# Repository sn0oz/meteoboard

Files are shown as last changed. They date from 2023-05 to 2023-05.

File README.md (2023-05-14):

mb-logo

# meteoboard - colorful weather forecast visualization 

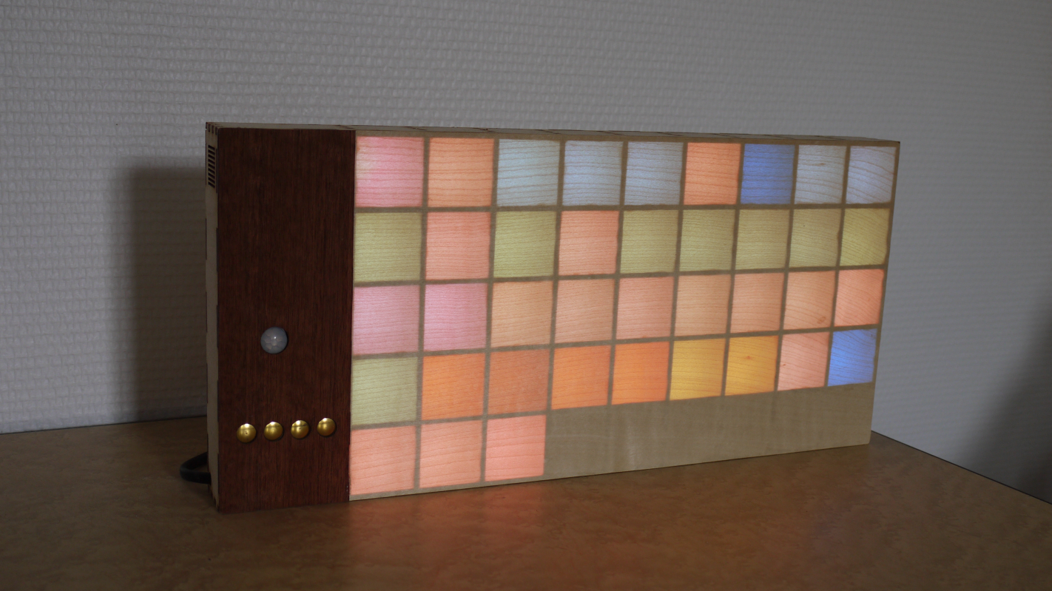
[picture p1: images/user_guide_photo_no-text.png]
mb-photo
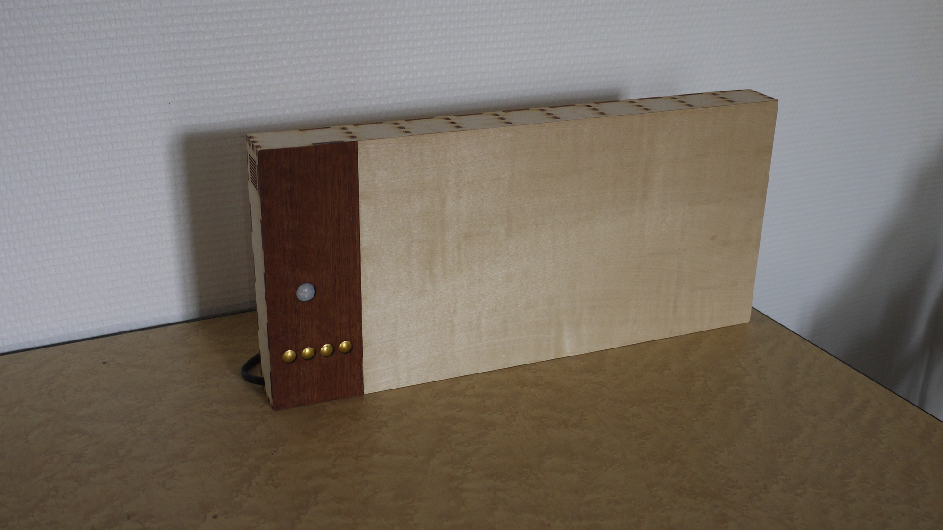
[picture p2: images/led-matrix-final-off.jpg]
mb off


meteoboard is a LED matrix displaying weather forecast with color mapping to weather condition or temperature values. for example sunny weather is obviously yellow and rain condition is represented with 3 shades of blue. see the user guide for detailed color/value mapping.
with a bit of practice it allows an instant knowledge of weather forecast, on a decorative object.

<figure>
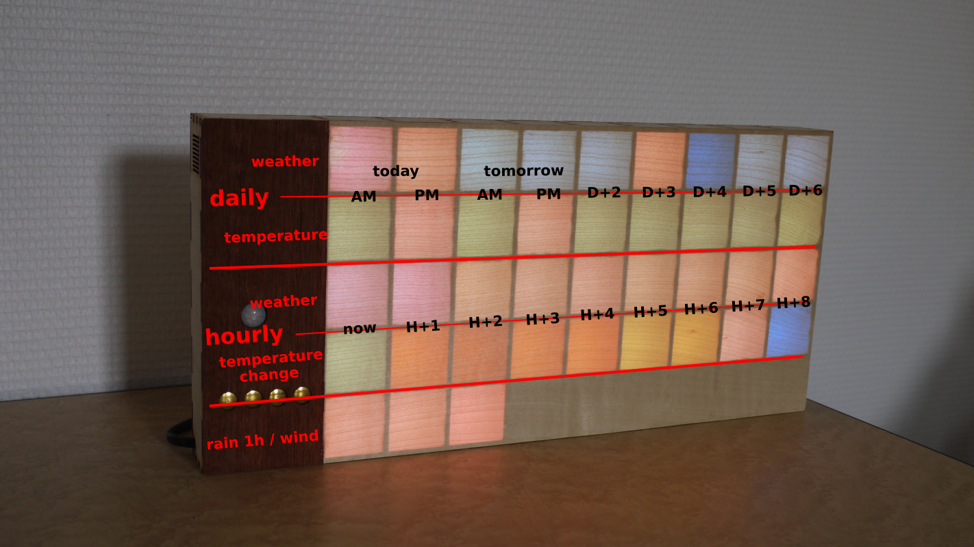
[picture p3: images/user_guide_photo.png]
user guide
    
    <figcaption>user guide</figcaption>
</figure>
<figure>
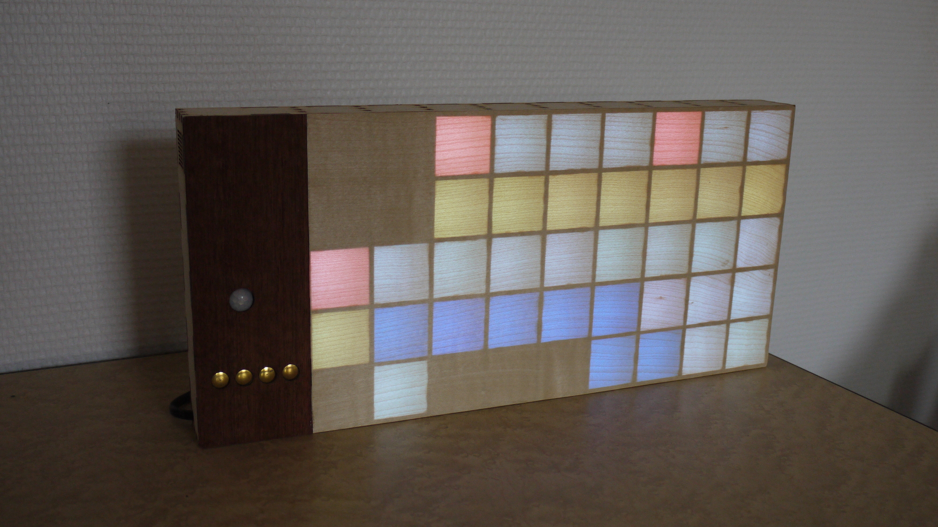
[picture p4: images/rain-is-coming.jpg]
rain is coming
    
    <figcaption>rain is coming</figcaption>
</figure>

the LED matrix can also be used to display various animations.

inspired by [maketvee's Wooden LED Gaming Display](https://www.instructables.com/Wooden-LED-Gaming-Display-Powered-by-Raspberry-Pi-/)

## features
- daily, hourly weather and temperature forecast + rain in the hour / current wind
- 4 touch buttons to control the display (change city, animation, ...)
- PIR and ambient light sensors to switch on only when necessary, at the right brightness

## usage

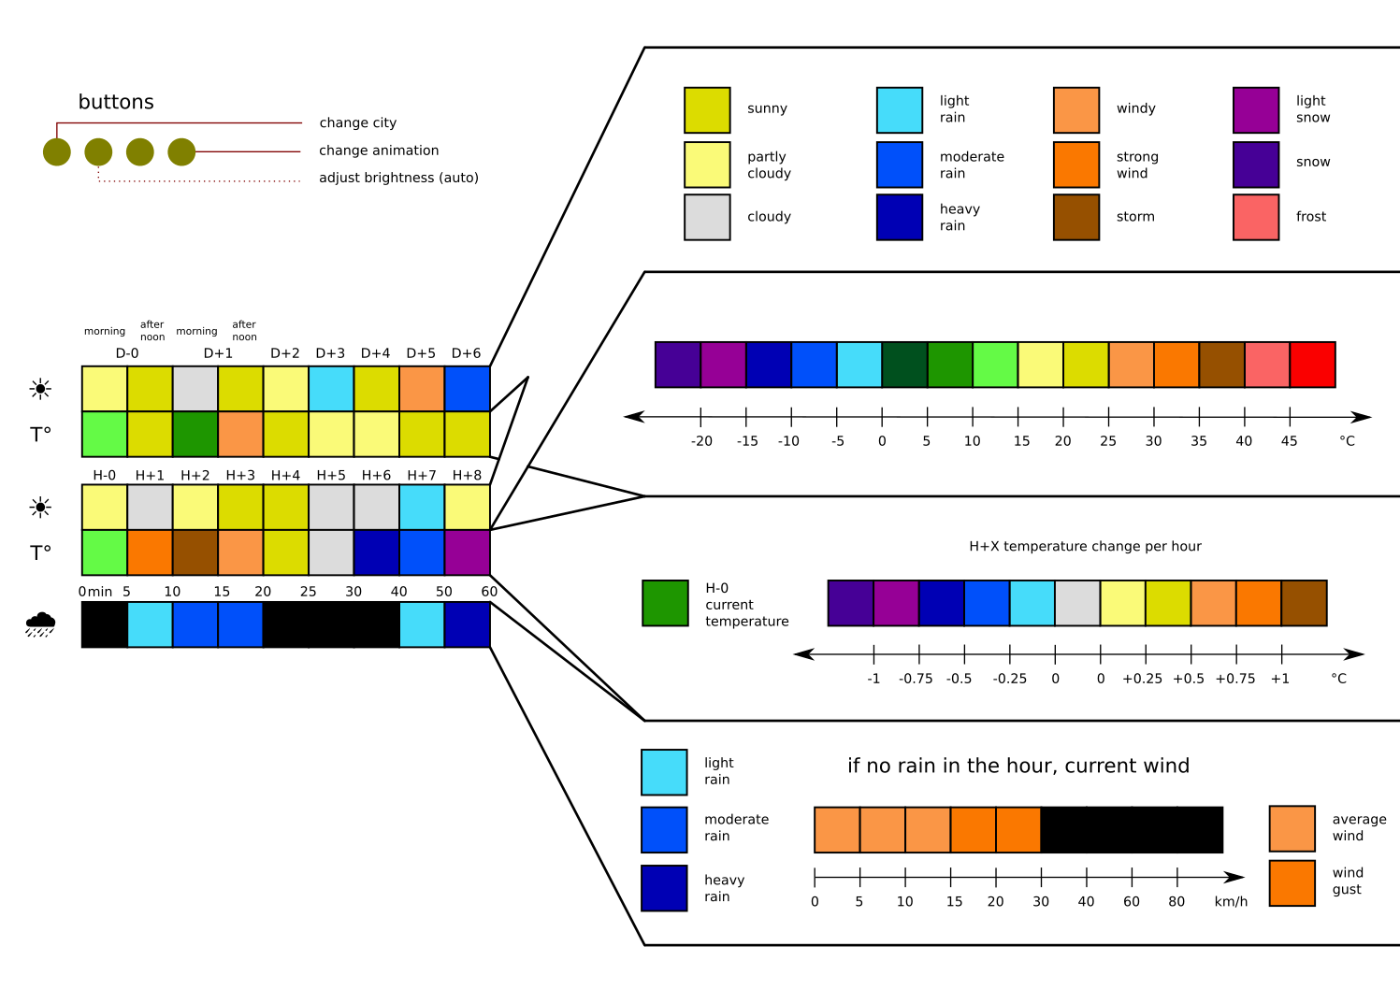
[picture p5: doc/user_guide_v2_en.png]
user guide en


## hardware

### case
[parametric wooden LED matrix](3d/)

### PCB
designed with KiCad
based on ESP32 it includes the sensors and allows to easily connect the LED strips.

## software
needs cleanup before releasing...

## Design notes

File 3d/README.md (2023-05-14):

# a parametric, veneer covered wooden LED matrix

includes casing for custom PCB based on ESP32 featuring LED driver, PIR and ambient light sensors, and touch buttons.
it can be wall mounted or just put on a flat surface.

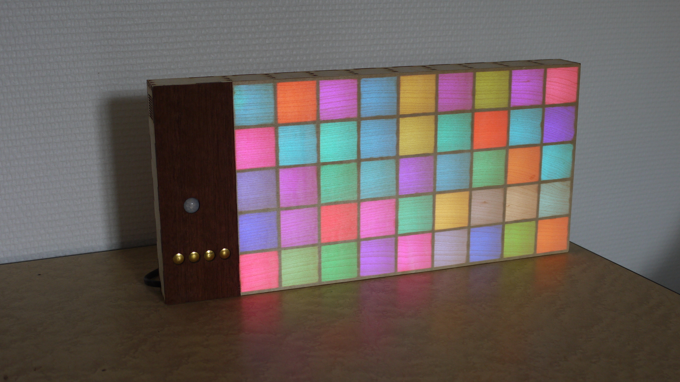
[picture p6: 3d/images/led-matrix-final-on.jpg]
led-matrix-final-on
led-matrix-final-off

inspired by: [maketvee's Wooden LED Gaming Display](https://www.instructables.com/Wooden-LED-Gaming-Display-Powered-by-Raspberry-Pi-/)
assisted by scripts from: [scottbez1's split-flap](https://github.com/scottbez1/splitflap/)

intended for weather forecast display but can be used for anything fitting the small resolution.

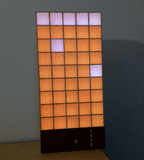
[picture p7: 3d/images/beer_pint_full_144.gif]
beer pint animation
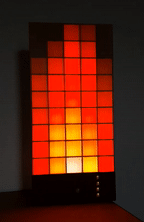
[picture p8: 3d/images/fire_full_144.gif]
fire animation


## **usage**
set parameters at the beginning of **board.scad** according to your needs. many parameters are available, including matrix resolution, wood thickness, kerf, ...
run **scripts/generate_2d.py** to generate SVG files for laser etching/engraving/marking/cutting.
you can adjust the kerf to fit your laser and other parameters with the script arguments.
the script render the 2d view of board.scad file and optimize the laser cutting by removing redundant lines.

## **recommended parameters**
the main dimension driver is the LED strip interval, which correspond to pixel height and width.
designed for 30 LED/m strip (33.3mm interval), it should be possible to use 60 or 15 LED/m strips however LED brightness might be insufficient for the later, depending on the veneer's light transmission.
however any pixel dimension is possible with other strip interval or by using standalone LEDs.
adjust the LED interval in led_ADA1376_dimensions.scad file accordingly.

## **design**
the parts placement is optimized to fit 2 A3 plywood sheets for a 9x5 pixels matrix.
if you change this resolution you might need to modify the last part of the board.scad script to fit your own resolution vs sheet dimensions.

### veneer
I used sycomore 0.3mm veneer - 0.6mm should allow enough light transmission.
choose whitest available wood veneer to limit color drift (can be compensated on software).

### touch buttons
intended to be hidden behind veneer, however extension veneer (0.6mm thick) doesn't allow reliable touch detection. 0.3mm veneer might work with carefull tuning of detection values to prevent false positive or undetected touches. I found it was easier to just cut the veneer and make buttons visible, while visually acceptable with their brass tacks shining.

### laser
adjust your laser parameters for each color/mode:
black: etch
orange: engrave (~1mm)
blue: mark
red: cut

## **assembly**
cut LED strip to length and lay on the back panel according to marking, taking care of data direction, **starting from top left**.
solder power and data cables: each strip is directly connected to power source, data follow a zig-zag way from top left.

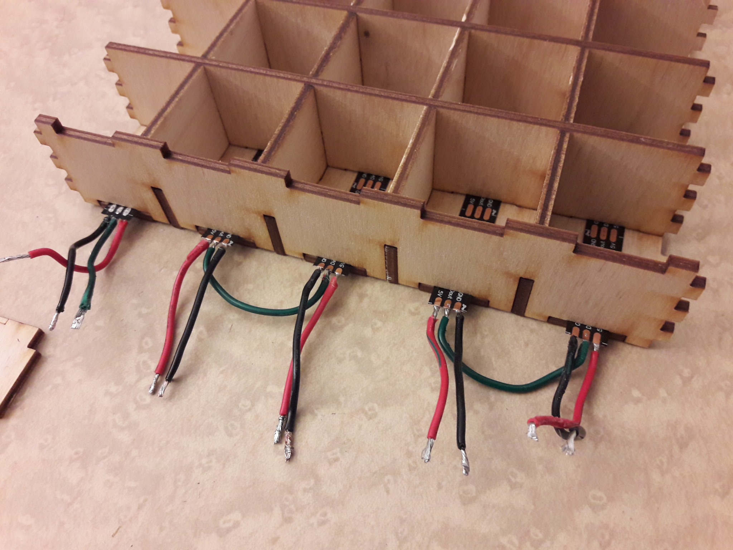
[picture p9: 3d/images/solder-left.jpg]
solder left
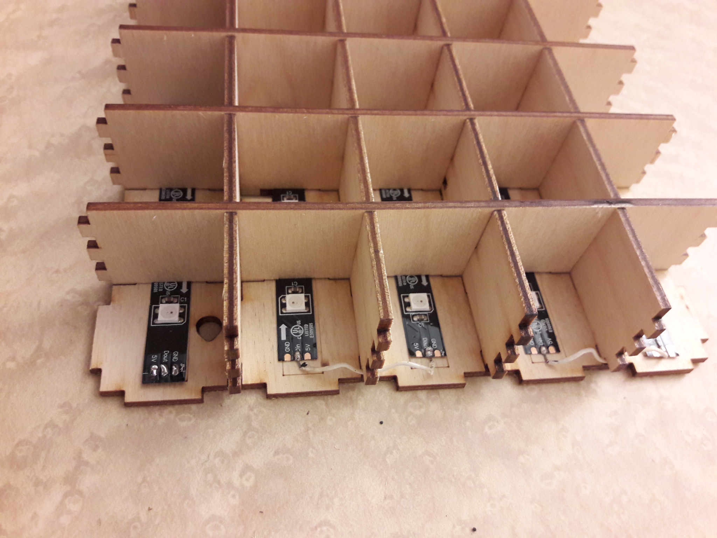
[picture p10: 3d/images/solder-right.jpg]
solder right


assemble the horizontal spacers first then vertical spacers

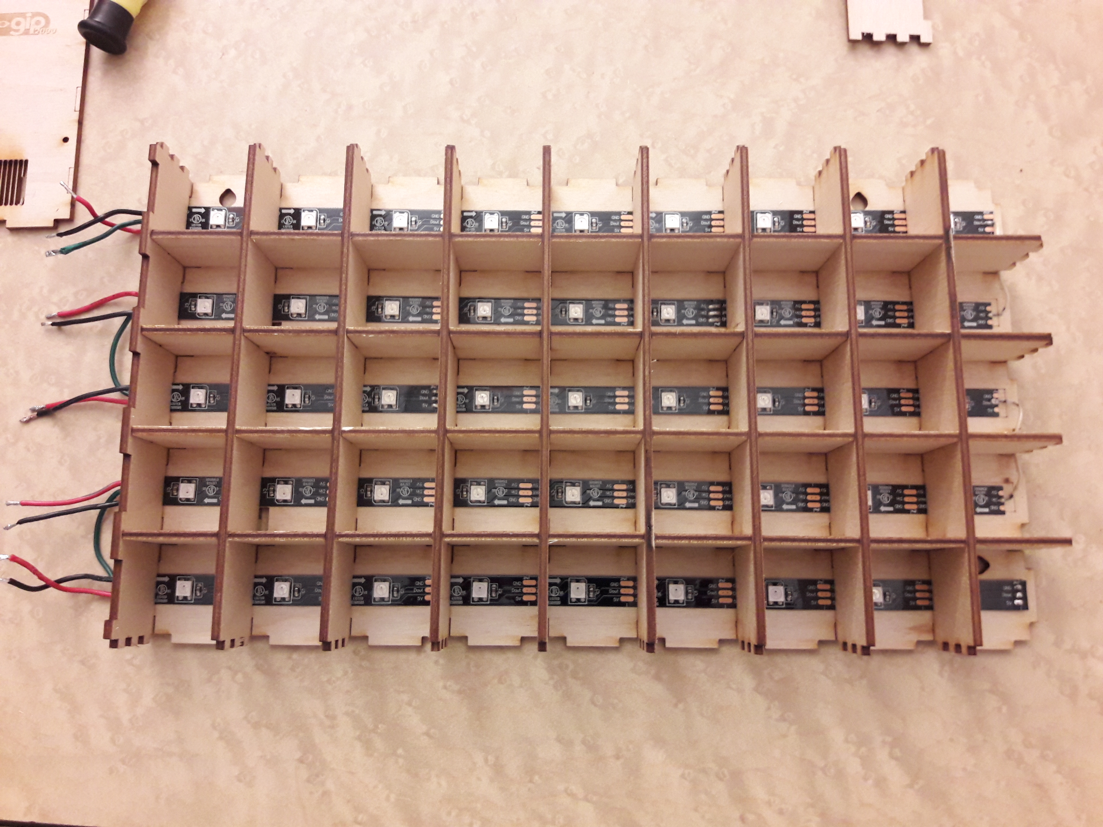
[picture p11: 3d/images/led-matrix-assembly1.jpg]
led-matrix-assembly1


then add the border panels, and the extension front panel (supporting the PCB).

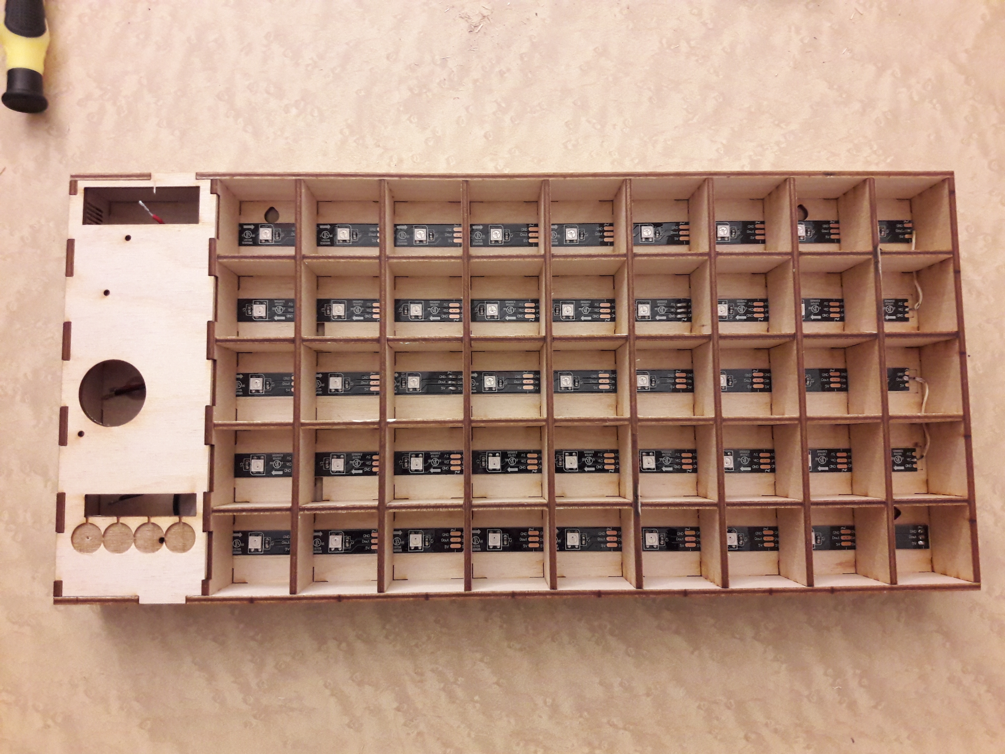
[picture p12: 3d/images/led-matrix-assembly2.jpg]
led-matrix-assembly2
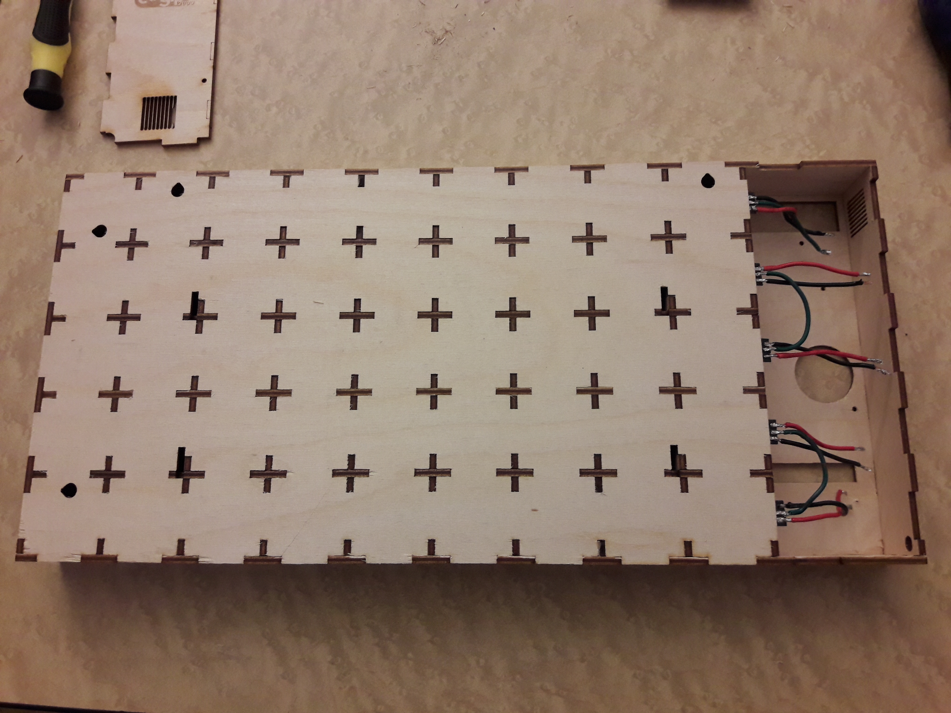
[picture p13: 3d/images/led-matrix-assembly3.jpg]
led-matrix-assembly3

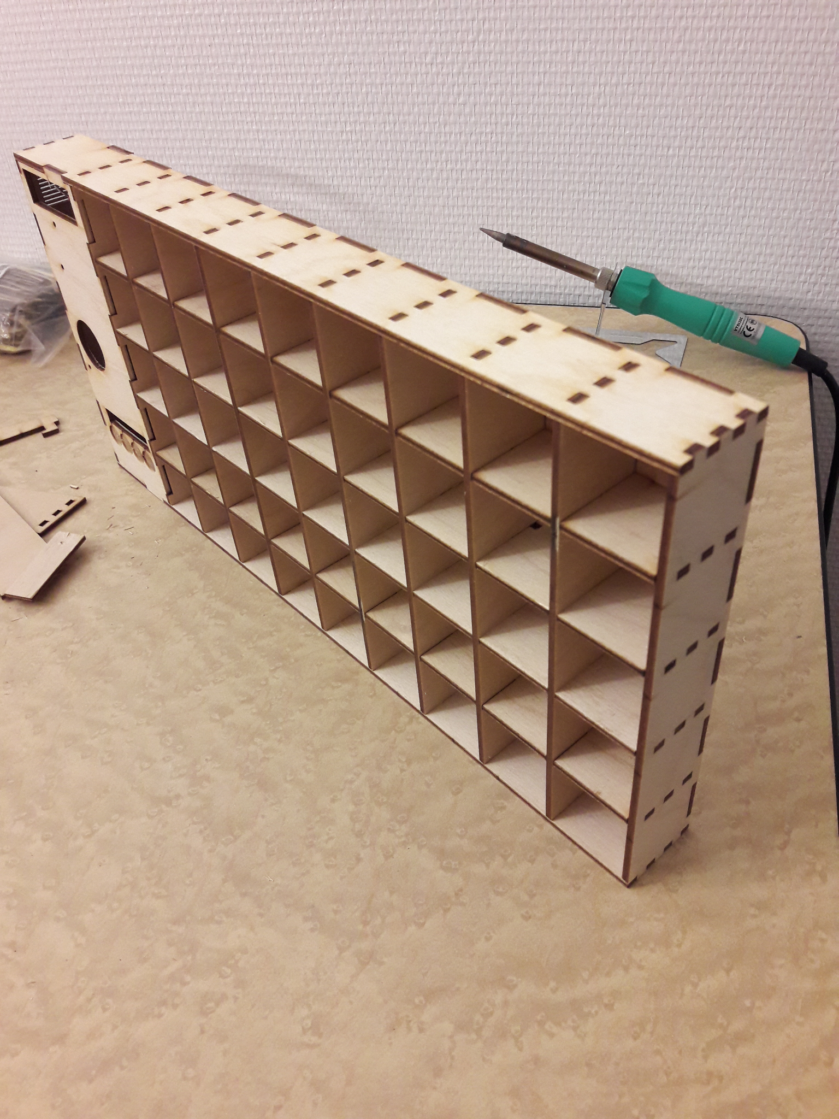
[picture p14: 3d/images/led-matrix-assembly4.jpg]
led-matrix-assembly4


place and connect the PCB, touch buttons (made from tacks with attached cables connected to GPIOs).

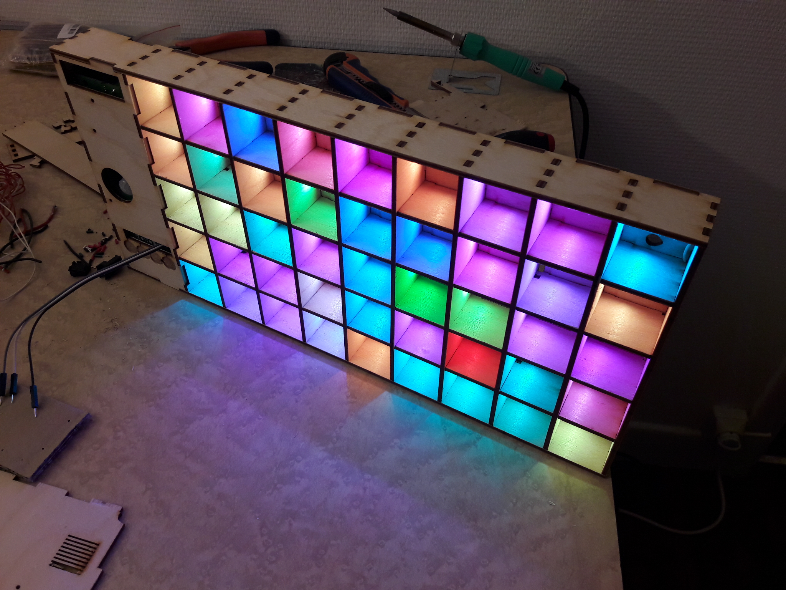
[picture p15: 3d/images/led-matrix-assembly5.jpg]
led-matrix-assembly5


eventually glue the wood veneer. I chose to use different woods for extension and LED matrix but you can use the same veneer (parameterized on the board.scad file).

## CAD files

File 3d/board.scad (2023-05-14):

use<pcb_MB2.scad>;
use<pir_SBC.scad>;
use<led_ADA1376.scad>;
use<label.scad>;
use<projection_renderer.scad>;

include<pcb_MB2_dimensions.scad>;
include<psu_IRM-15-X_dimensions.scad>;
include<pir_SBC_dimensions.scad>;
include<led_ADA1376_dimensions.scad>;

version = "2.1.1";

testing = false;
explosion = 0;

render_3d = true;
render_back_panel = true;
render_electronics = true;
render_front_panel_veneer = true;
render_unmounted_support = true;

// board parameters
pixels_h = 9;
pixels_v = 5;
thickness = 3;
veneer_thickness = 0.3;
num_touch_buttons = 4;
touch_button_radius = 4.5;
front_panel_bicolor = true;
pixel_width = led_interval;
pixel_height = pixel_width;
echo(pixel_width = pixel_width);

// assembly parameters
side_panel_num_notches = 7;
pcb_num_notches = 5;
bp_notch_length = 6;
pcb_clearance = 1;
cable_clearance = 12;
vents_number = 7;
vents_width = 1;
power_cable_position = 0;   // 0 = both, 1 = left, 2 = bottom
power_cable_hole_radius = 3;
buttons_height = pixel_height + thickness;
logo_scale_factor = 1.5;

// 2d parameters
render_index = -1;
render_etch = true;
render_mark = true;
render_engrave = true;
panel_horizontal = 0;
panel_vertical = 0;
render_2d_mirror = false;
a3_fit_offset = 20;

// Remember: it's better to underestimate (looser fit) than overestimate (no fit)
kerf = 0.12;

$fn = 60;

wood = [0.76, 0.6, 0.42];
sycomore = [0.9, 0.85, 0.75];
cherrywood = [0.2, 0.15, 0.2];
etch_color = [0, 0, 0];
mark_color = [0.2, 0.4, 0.6];
engrave_color = [0.85, 0.4, 0];

etch_depth = 0.1;
mark_depth = 0.1;
engrave_depth = 0.1;

// "Epsilon" - a small error tolerance value, used when designing 3d parts to avoid 
// exact complanar faces that cause OpenSCAD rendering artifacts
// See https://3dprinting.stackexchange.com/a/9795
eps = 0.01;

// CHANGELOG v2.1.1
// wall mounted holes gap identical for horizontal and vertical positions
// separator_v0 led cable notches
// power cable hole choice


// TODO: mark helpers and reminders (separators, ...)



// PCB position
pcb_x = thickness + pcb_clearance;
pcb_y = thickness + cable_clearance/2;

// board dimensions
extension_width = pcb_x + pcb_width + cable_clearance;
echo(extension_width = extension_width);

board_height = thickness + pcb_height + psu_height + pcb_clearance + thickness;
echo(board_height=board_height);
board_width = pixels_v*pixel_height + thickness;
echo(board_width = board_width);
board_length = extension_width + pixels_h*pixel_width + thickness;
echo(board_length = board_length);

// common notch width for panel assembly
notch_width = board_height / side_panel_num_notches;

// unmounted support height
um_support_h = (pixels_v-2)*pixel_height + 4*thickness;


if (!testing) {
    assert(board_width >= pcb_y + pcb_length + pcb_clearance,
                                                "Insufficient panel height for PCB !");
    assert(board_length + extension_width + 2*kerf < 418,
                                                "A3 part 1 length overrun !");
    assert(12*board_height + 11*kerf < 416,
                                                "A3 part 2 length overrun !");
    assert(board_width + 3*board_height + 3*kerf < 293,
                                                "A3 part 1 width overrun !");
    assert(board_width + um_support_h + kerf < 293,
                                                "A3 part 2 width overrun !");
}



module copyleft() {
    text(text=str("meteoboard v", version), font = "Roboto", size = 4, valign = "center",
                                                halign = "center");
}

module logo(scale_factor, centered = false) {
    logo_length = 6;
    logo_width = 5;
    if (centered) {
        translate([-logo_length*scale_factor/2, -logo_width*scale_factor/2])
            scale([scale_factor, scale_factor])
                import("images/mb_logo_b&w.svg");
    }
    else {
        scale([scale_factor, scale_factor])
            import("images/mb_logo_b&w.svg");
    }
}

module laser_mirror() {
    if (render_2d_mirror) {
        mirror([1, 0, 0])
            children();
    }
    else {
        children();
    }
}

module laser_etch_style() {
    color(etch_color)
        linear_extrude(height=etch_depth)
            children();
}

module laser_mark_style() {
    color(mark_color)
        linear_extrude(height=mark_depth)
            children();
}

module laser_engrave_style() {
    color(engrave_color)
        linear_extrude(height=engrave_depth)
            children();
}

module air_vents_2d() {
    hull() {
        translate([0, vents_width/2])
            circle(vents_width/2);
        translate([board_height-5*thickness-vents_width, vents_width/2])
            circle(vents_width/2);
    }
}

module wall_mount_hole() {
    hull() {
        circle(3);
        translate([0, 3])
            circle(1);
    }
}

module hook() {
    union() {
        square([3*thickness, 2*thickness]);
        translate([2*thickness, -thickness])
            square(thickness);
    }
}

module unmounted_support_cap() {
    color(wood) {
        linear_extrude(height=thickness) {
            union() {
                hook();
                translate([2*thickness, 2*thickness])
                    square(thickness);
            }
        }
    }
}

module unmounted_support() {
    color(wood) {
        linear_extrude(height=thickness) {
            difference() {
                h = um_support_h;
                union() {
                    polygon([[-board_height,0], [0,0], [0,h], [-2*thickness,h]]);
                    translate([0, pixel_height + thickness])
                        hook();
                    translate([0, h - 3*thickness])
                        hook();
                }

                // link notches
                for (i = [2:2:side_panel_num_notches-1]) {
                    translate([-notch_width*i, thickness])
                        square([notch_width, thickness]);
                }
            }
        }
    }
}


module unmounted_support_link() {
    color(wood) {
        linear_extrude(height=thickness) {
            difference() {
                len = (pixels_h-3)*pixel_width + thickness;
                square([len, board_height]);
                
                // unmounted support notches
                for (i = [0:2:side_panel_num_notches-1]) {
                    translate([0, notch_width*i])
                        square([thickness, notch_width]);
                    translate([len - thickness, notch_width*i])
                        square([thickness, notch_width]);
                }
            }
        }
    }
}


module extension_panel_2d() {
    difference() {
        square([extension_width - kerf, board_width]);
        
        // side panel notches
        for (i = [0:pixels_v]) {
            translate([0, i*pixel_width - bp_notch_length])
                square([thickness, 2*bp_notch_length + thickness]);
        }
        
        // top & bottom panel notches
        translate([extension_width - bp_notch_length, 0])
            square([bp_notch_length, thickness]);
        translate([extension_width - bp_notch_length, board_width - thickness])
            square([bp_notch_length, thickness]);
        square([extension_width - pixel_width + bp_notch_length + thickness, thickness]);
        translate([0, board_width - thickness])
            square([extension_width - pixel_width + bp_notch_length + thickness, thickness]);
    }
}


module extension_back_panel() {
    // takedown back panel for maintenance
    color(wood) {
        linear_extrude(height=thickness) {
            difference() {
                extension_panel_2d();

                // screw holes
                for (i = [1, pixels_v-1]) {
                    translate([extension_width - thickness, 
                                        pixel_height*i + thickness/2])
                        circle(1);
                }

                // air vents
                for (i = [0:vents_number-1]) {
                    translate([(extension_width - 5*thickness + vents_width)/2,
                                            3*thickness + (2*i+1)*vents_width])
                        air_vents_2d();
                }
                

                // power cable hole
                translate([thickness + 0.5*power_cable_hole_radius, thickness + 0.5*power_cable_hole_radius])
                    circle(1.25*power_cable_hole_radius);
            }
        }
    }
}


module extension_front_panel() {
    // PCB support panel
    color(wood) {
        linear_extrude(height=thickness) {
            difference() {
                union() {
                    extension_panel_2d();
                    translate([extension_width - kerf, thickness])
                        square([kerf + thickness, board_width - 2*thickness]);                
                }
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

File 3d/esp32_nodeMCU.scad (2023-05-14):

include<esp32_nodeMCU_dimensions.scad>;

module ESP32_nodeMCU() {
    $fn = 30;

    eps = 0.01;

    black = [0.05, 0.05, 0.05];
    gray = [0.5, 0.5, 0.5];

    module chassis() {
        color(gray) {
            translate([0, 0, 0]) {
                cube([esp32_length, esp32_width, esp32_height]);
            }
        }
    }

    module pin() {
        union() {
            color(black) {
                cube(2.54);
            }
            translate([2.54/2, 2.54/2, 2.54]) {
                color(gray) {
                    cube([0.5, 0.5, 6]);
                }
            }
        }
    }

    module pin_header() {
        union() {
            for (i = [0:14]) {
                translate([i*2.54, 0, 0])
                    pin();
            }
        }
    }

    module screw_hole() {
        cylinder(esp32_height + eps, d=2*esp32_screw_hole_radius);
    }

    difference() {
        chassis();
        screw_hole_distance = esp32_screw_hole_radius + esp32_screw_hole_margin;
        for (i = [screw_hole_distance, esp32_length - screw_hole_distance]) {
            for (j = [screw_hole_distance, esp32_width - screw_hole_distance]) {
                translate([i, j, -eps/2])
                    screw_hole();
            }
        }
    }
    translate([4.5, 2.54, 0])
        rotate([180, 0, 0])
            pin_header();
    translate([4.5, esp32_width, 0]) 
        rotate([180, 0, 0])
            pin_header();
}

// Example usage:
ESP32_nodeMCU();

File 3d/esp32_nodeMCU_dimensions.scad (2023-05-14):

// ESP32 NodeMCU dimensions
esp32_height = 5;
esp32_width = 28.2;
esp32_length = 51.5;

esp32_screw_hole_radius = 1.6;
esp32_screw_hole_margin = 1;

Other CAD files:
3d/led_ADA1376.scad
3d/label.scad
3d/led_ADA1376_dimensions.scad
3d/pcb_MB2.scad
3d/pcb_MB2_dimensions.scad
3d/pir_SBC.scad
3d/pir_SBC_dimensions.scad
3d/projection_renderer.scad
3d/psu_IRM-15-X.scad
3d/psu_IRM-15-X_dimensions.scad
